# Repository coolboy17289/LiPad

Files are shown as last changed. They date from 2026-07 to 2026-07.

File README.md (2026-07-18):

# LiPad

# Features

## Hardware

- Custom-designed PCB
- Compact macropad layout
- RP2040-based controller support
- Mechanical key switches
- Rotary encoder with push button
- 14x SK6812 MINI addressable RGB LEDs
- Custom LED positioning for animations
- Designed using KiCad

## Firmware

LiPad uses:

- CircuitPython
- KMK Firmware
- NeoPixel RGB control

Current firmware features:

- Programmable key layers
- Media controls
- Rotary encoder volume control
- Encoder button actions
- RGB lighting effects
- Idle lighting mode
- Custom keyboard matrix support

---

# Project Structure

```
LiPad/
├── PCB/
│   ├── KiCad schematic files
│   ├── PCB layout files
│   └── 3D model files
│
├── Code/
│   ├── main.py
│   ├── kb.py
│   ├── code.py
│   └── requirements.txt
│
├── README.md
├── .gitignore
└── .vscode/
    └── settings.json
```

---

# Firmware

The LiPad firmware is separated into hardware configuration and keyboard behaviour.

## code.py

`code.py` is the CircuitPython startup file.

When the controller powers on, CircuitPython automatically runs this file to start the keyboard firmware.

---

## main.py

`main.py` contains the main functionality of LiPad.

It controls:

- Keyboard keymaps
- Layers
- Rotary encoder functions
- Encoder button behaviour
- RGB lighting effects
- Idle detection
- Keyboard events

The main firmware logic is designed to be easy to edit and customise without changing the hardware configuration.

---

## kb.py

`kb.py` defines the physical hardware of LiPad.

It contains:

- Matrix row pins
- Matrix column pins
- Diode orientation
- LED configuration
- LED count
- LED physical positions

This separation allows the firmware logic to change without needing to rewrite the hardware setup.

---

# Keyboard Layers

LiPad currently includes three layers.

## Layer 0 - Main

Default controls:

| Key | Function |
|---|---|
| Key 1 | Previous track |
| Key 2 | Play/Pause |
| Key 3 | Next track |

---

## Layer 1 - Utility

Additional shortcuts:

| Key | Function |
|---|---|
| Key 1 | Media select |
| Key 2 | Calculator |
| Key 3 | Windows Run |

# RGB Lighting

LiPad uses 14 SK6812 MINI addressable RGB LEDs.

The firmware supports multiple lighting modes:

## Solid

A breathing effect using the active layer colour.

## Rainbow

A moving rainbow animation across the LED layout.

## Wave

A wave animation based on the LED positions.

## Reactive

A bright reactive lighting mode.

## Idle

A low-power animation used when the keyboard has not been used for a period of time.

# PCB Design

The PCB for LiPad was designed using KiCad.

The PCB directory contains:

- Schematic files
- PCB layout
- Component footprints
- 3D model exports
- Design reports

The design was created with custom placement and routing to support the LiPad layout.

# Development

## Requirements

Development requires:

- Linux, Windows, or macOS
- Python 3
- Git
- VS Code recommended
- CircuitPython compatible controller

## Installing Development Tools

Navigate to the firmware folder:

```bash
cd Code
```

Install requirements:

```bash
python3 -m pip install -r requirements.txt
```

# Building Firmware

After preparing the CircuitPython controller:

1. Connect the board through USB
2. Enter bootloader mode
3. Copy the firmware files to the `CIRCUITPY` drive

Required files:

```
CIRCUITPY/
├── code.py
├── main.py
├── kb.py
└── lib/
```

# Future Plans

Possible future improvements:

- [ ] Custom LiPad case
- [ ] OLED display support
- [ ] More programmable layers
- [ ] Configuration software
- [ ] VIA/Vial compatibility
- [ ] Wireless support
- [ ] Improved RGB effects
- [ ] Build documentation
- [ ] Manufacturing files

# Contributing

Contributions are welcome.

If you would like to improve LiPad:

1. Fork the repository
2. Create a new branch

# License

LiPad is an open-source hardware and firmware project.

License information will be added before the first official release.

# Author

Created by **Lihan Badenhorst**

Project: **LiPad**

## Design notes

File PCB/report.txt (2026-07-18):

Plotted to '/home/Lihan/LiPad/PCB/gerbers/LiPad-F_Cu.gtl'.
Plotted to '/home/Lihan/LiPad/PCB/gerbers/LiPad-B_Cu.gbl'.
Plotted to '/home/Lihan/LiPad/PCB/gerbers/LiPad-F_Silkscreen.gto'.
Plotted to '/home/Lihan/LiPad/PCB/gerbers/LiPad-B_Silkscreen.gbo'.
Plotted to '/home/Lihan/LiPad/PCB/gerbers/LiPad-F_Mask.gts'.
Plotted to '/home/Lihan/LiPad/PCB/gerbers/LiPad-B_Mask.gbs'.
Plotted to '/home/Lihan/LiPad/PCB/gerbers/LiPad-Edge_Cuts.gm1'.
Created Gerber job file '/home/Lihan/LiPad/PCB/gerbers/LiPad-job.gbrjob'.
Info: Done.

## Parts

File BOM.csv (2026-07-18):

Component | Qty
XIAO RP2040 | 1
SK6812 Mini LEDs | 14
Rotary Encoder | 1
Cherry MX Switches | 9
PCB | 1
Diodes (1N4148) | 9
M3x8 Bolt | 4
1U Keycaps | 9
KMK Firmware | 1
PCB | 1
Case Top.stl | 1
Case Bottom.stl | 1
Knob.stl | 1

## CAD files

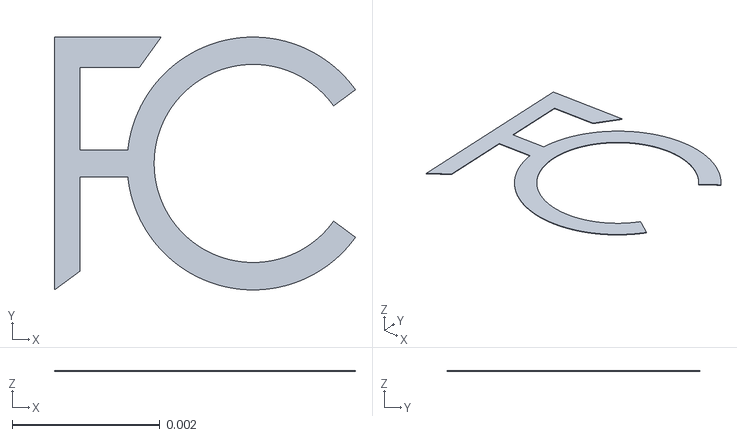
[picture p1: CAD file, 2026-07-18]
stl's/v1 do not use/Assembly 2 - Seeed Studio XIAO RP2040 v26 (20).stl
0.00407 x 0.00342 x 1e-05

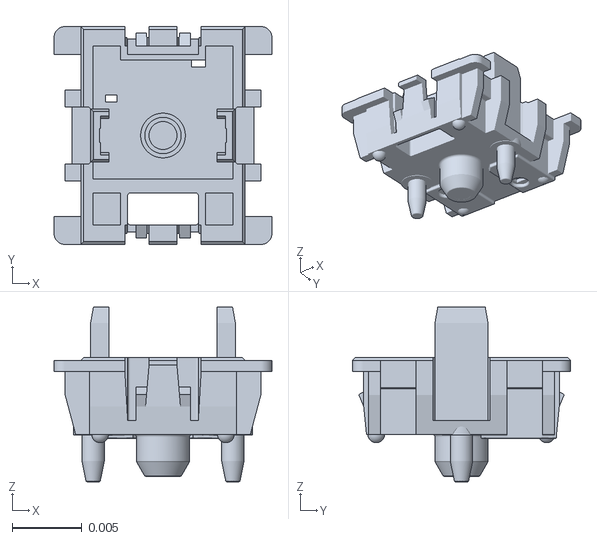
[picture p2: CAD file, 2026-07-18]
stl's/v1 do not use/Assembly 2 - SW_Cherry_MX_PCB_cp_6 (1).stl
0.0156 x 0.0156 x 0.0125

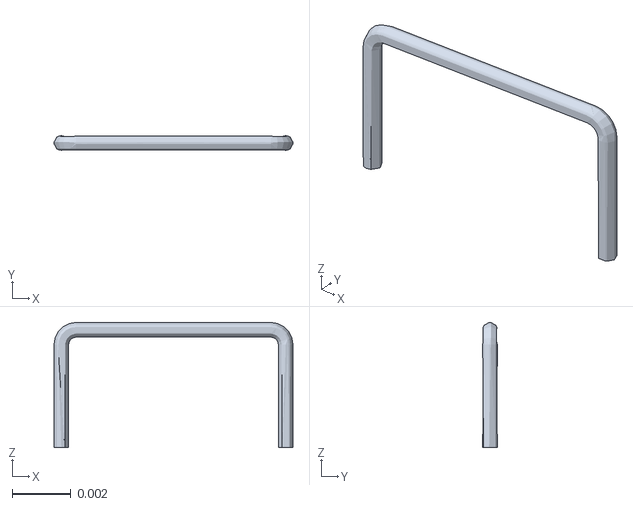
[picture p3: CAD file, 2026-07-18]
stl's/Main/Assembly 2 - D_DO-35_SOD27_P7.62mm_Horizontal.stl
0.00812 x 0.0005 x 0.00425

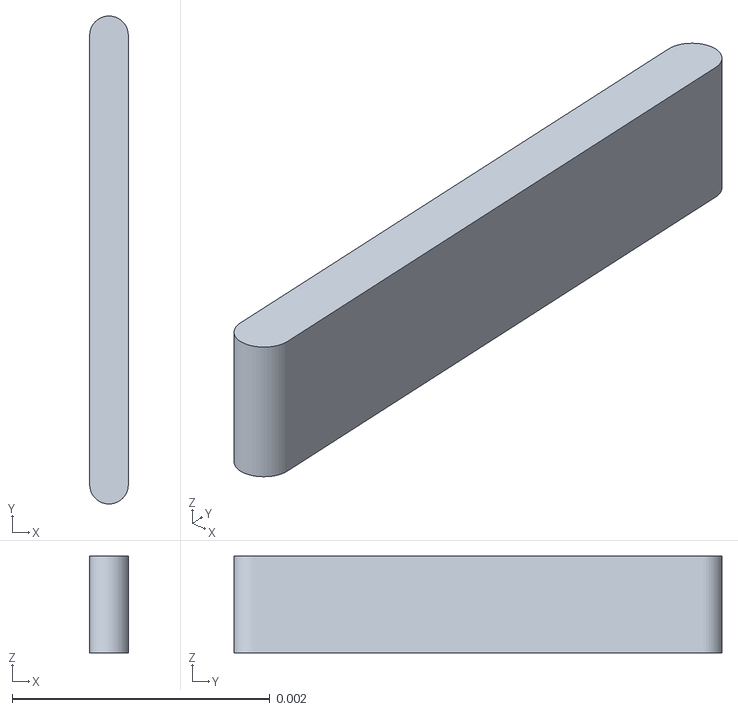
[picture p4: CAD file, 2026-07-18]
stl's/v1 do not use/Assembly 2 - Seeed Studio XIAO RP2040 v26 (24).stl
0.0003 x 0.00378 x 0.00075

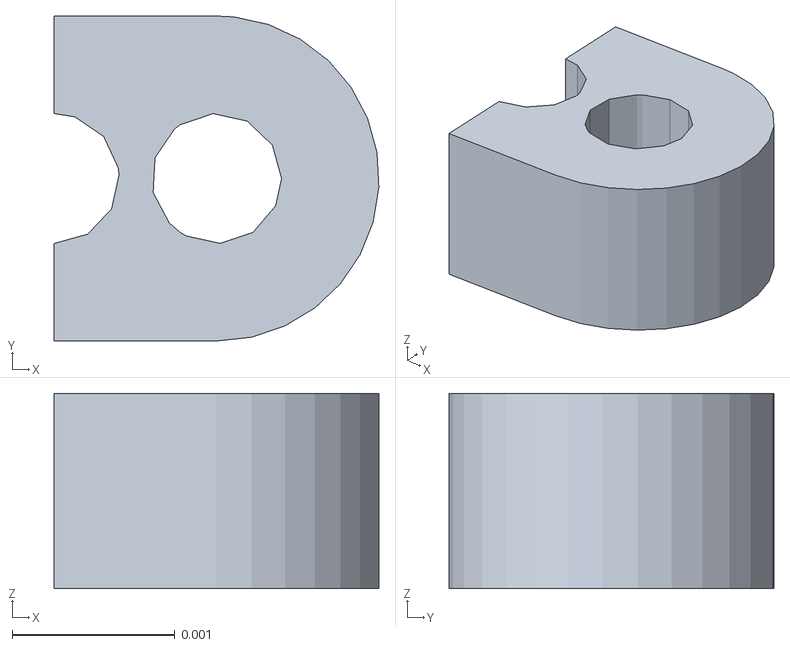
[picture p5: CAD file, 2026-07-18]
stl's/Main/Assembly 2 - Seeed Studio XIAO RP2040 v26 (57).stl
0.002 x 0.002 x 0.0012

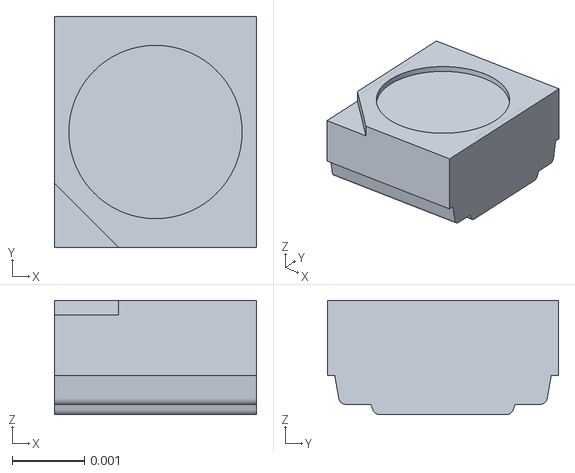
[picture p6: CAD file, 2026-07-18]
stl's/v1 do not use/Assembly 2 - Body_9.stl
0.0028 x 0.0032 x 0.00158

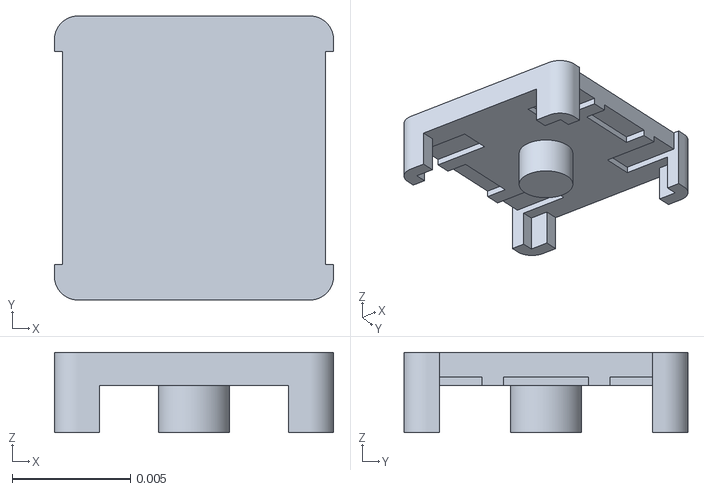
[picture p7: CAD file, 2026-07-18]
stl's/v1 do not use/Assembly 2 - Part 8.stl
0.0118 x 0.012 x 0.0034

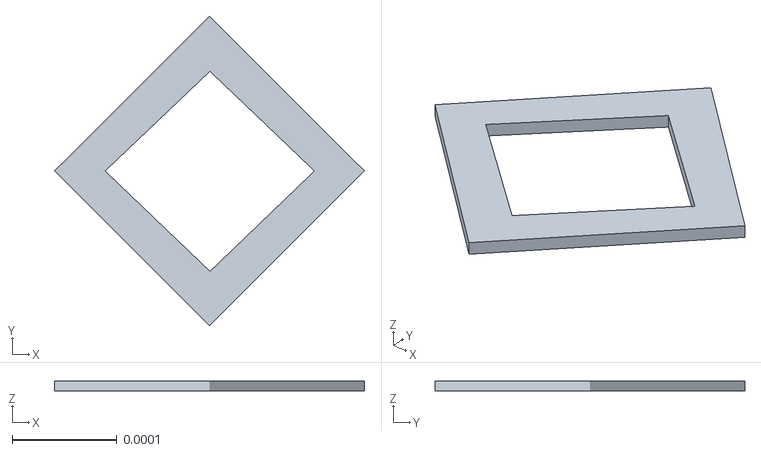
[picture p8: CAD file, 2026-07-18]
stl's/Main/Assembly 2 - Seeed Studio XIAO RP2040 v26 (34).stl
0.000295 x 0.000295 x 1e-05

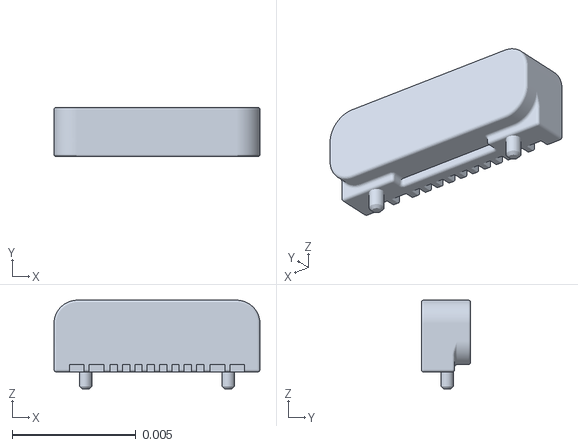
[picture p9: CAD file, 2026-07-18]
stl's/v1 do not use/Assembly 2 - Seeed Studio XIAO RP2040 v26 (21).stl
0.00834 x 0.002 x 0.00359

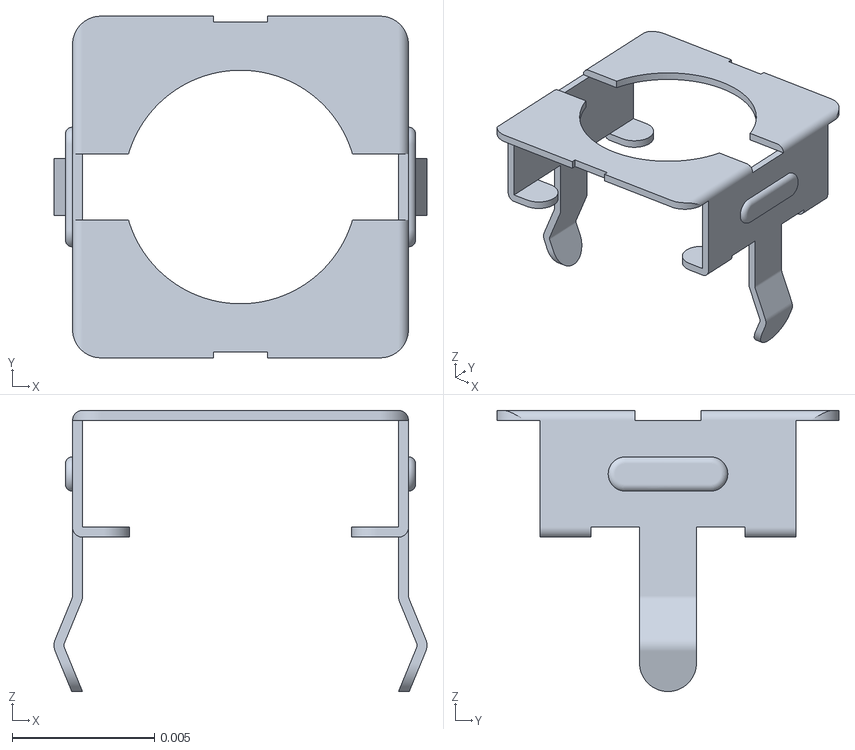
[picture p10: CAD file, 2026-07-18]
stl's/v1 do not use/Assembly 2 - Part 6.stl
0.0131 x 0.012 x 0.00987

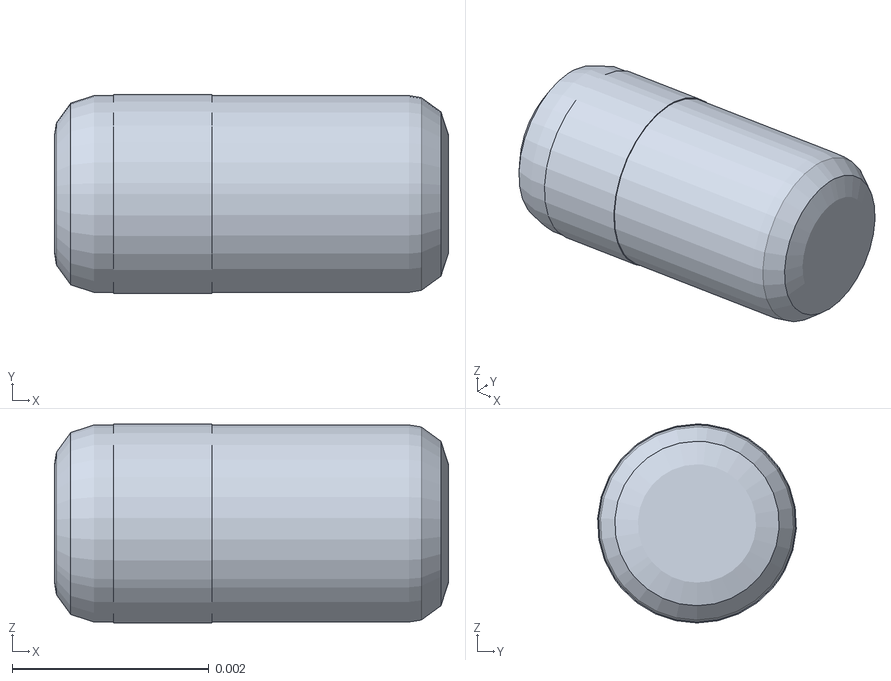
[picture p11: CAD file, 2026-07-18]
stl's/Main/Assembly 2 - D_DO-35_SOD27_P7.62mm_Horizontal_6.stl
0.004 x 0.00202 x 0.00202

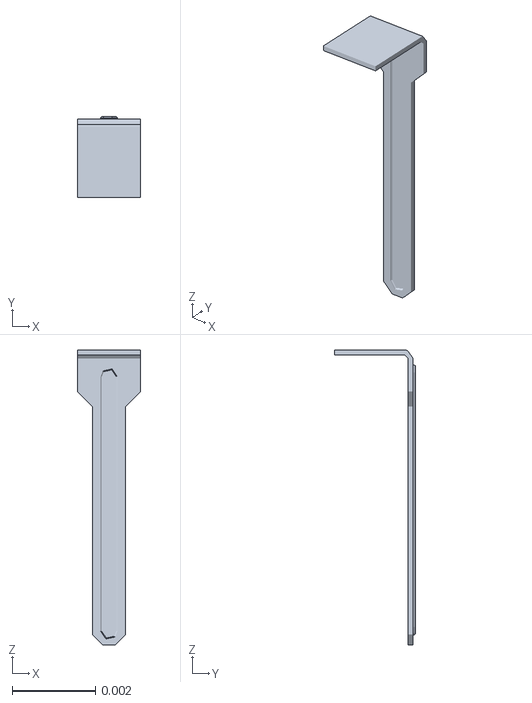
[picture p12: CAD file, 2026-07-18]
stl's/Main/Assembly 2 - Part 3.stl
0.0015 x 0.00193 x 0.00707

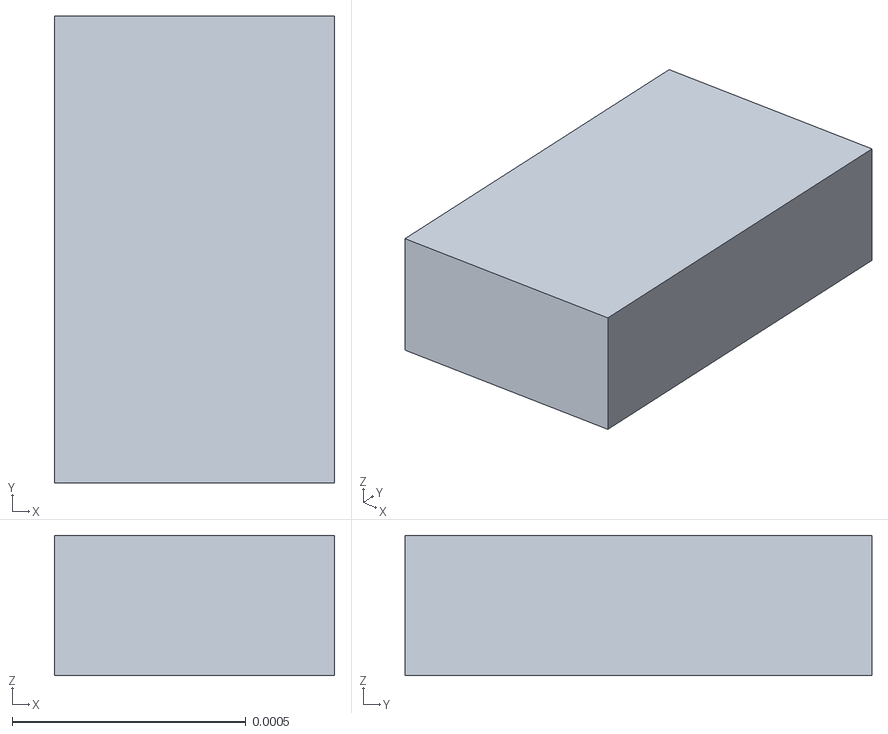
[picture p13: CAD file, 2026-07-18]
stl's/v1 do not use/Assembly 2 - Seeed Studio XIAO RP2040 v26 (74).stl
0.0006 x 0.001 x 0.0003

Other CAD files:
stl's/v1 do not use/Assembly 2 - Seeed Studio XIAO RP2040 v26 (53).stl
stl's/Main/Assembly 2 - Seeed Studio XIAO RP2040 v26 (42).stl
stl's/v1 do not use/Assembly 2 - Seeed Studio XIAO RP2040 v26 (82).stl
stl's/v1 do not use/Assembly 2 - Seeed Studio XIAO RP2040 v26 (67).stl
stl's/Main/Assembly 2 - Seeed Studio XIAO RP2040 v26 (51).stl
PCB/3D Models/MX_Switch.step
PCB/3D Models/SK6812MINI-E.step
PCB/3D Models/Seeed_Studio_XIAO_RP2040_v26.step
stl's/Main/Assembly 2 - Body.stl
stl's/Main/Assembly 2 - Body_1.stl
stl's/Main/Assembly 2 - Body_10.stl
stl's/Main/Assembly 2 - Body_11.stl
stl's/Main/Assembly 2 - Body_12.stl
stl's/Main/Assembly 2 - Body_13.stl
stl's/Main/Assembly 2 - Body_2.stl
stl's/Main/Assembly 2 - Body_3.stl
stl's/Main/Assembly 2 - Body_4.stl
stl's/Main/Assembly 2 - Body_5.stl
stl's/Main/Assembly 2 - Body_6.stl
stl's/Main/Assembly 2 - Body_7.stl
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

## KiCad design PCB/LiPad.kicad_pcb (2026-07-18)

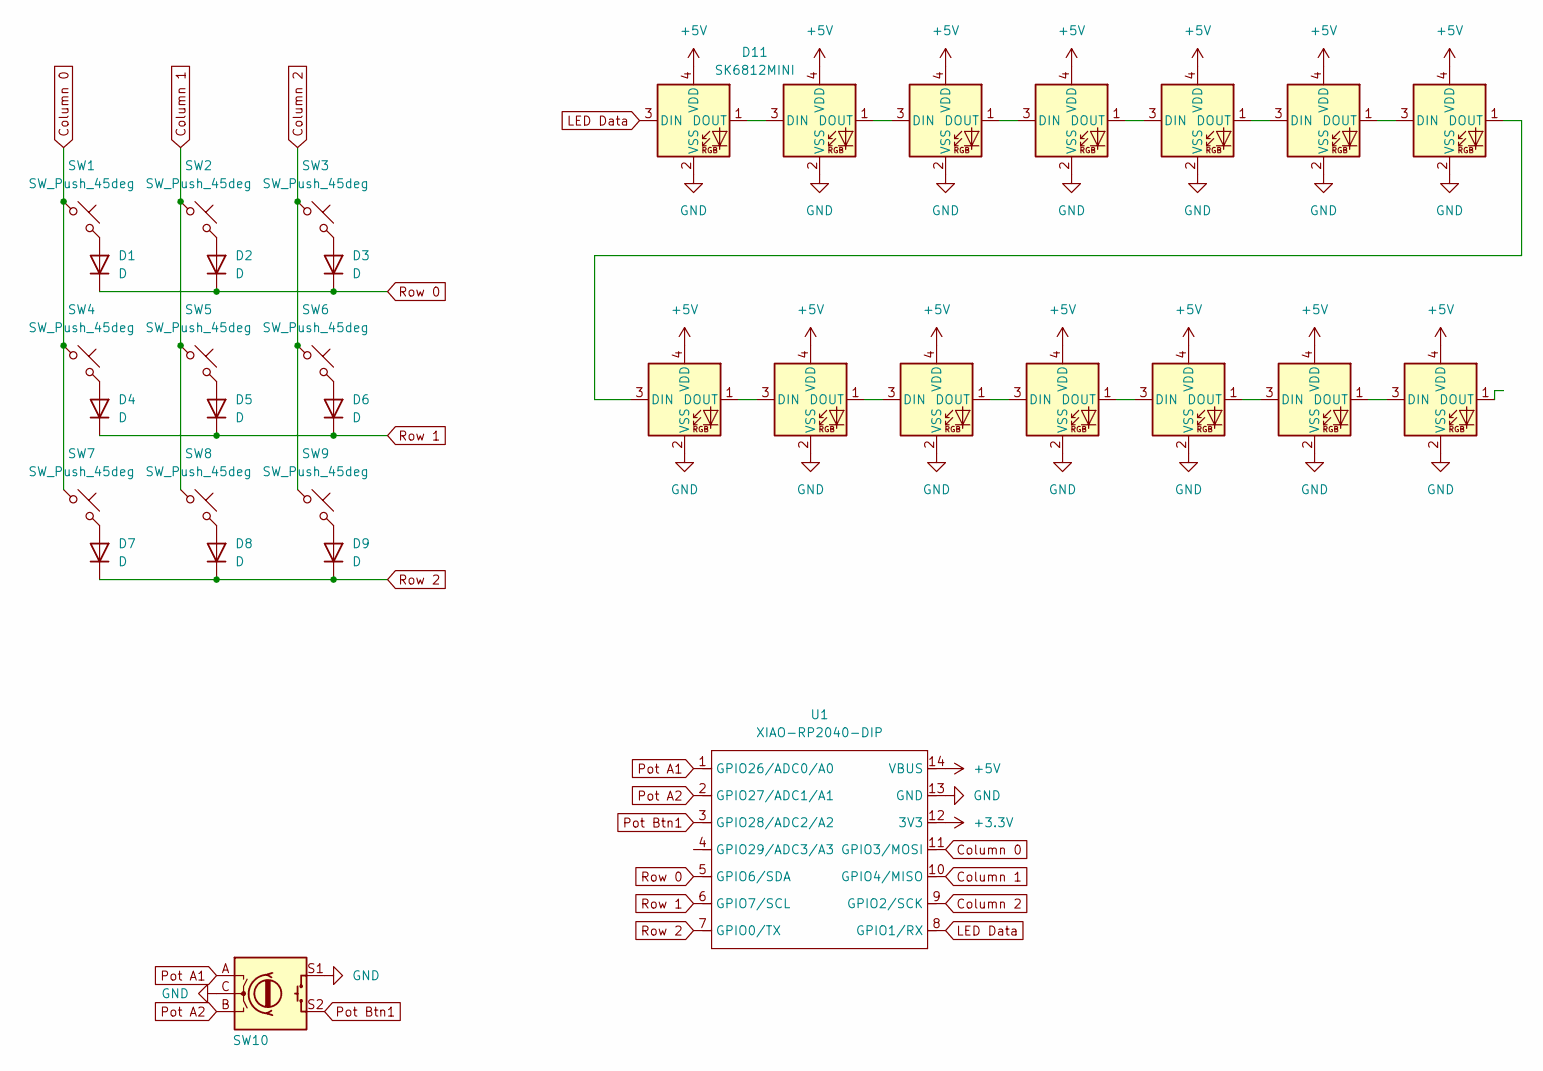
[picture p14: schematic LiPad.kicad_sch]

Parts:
D1, D2, D3, D4, D5, D6, D7, D8, D9: D; D_DO-35_SOD27_P7.62mm_Horizontal
D10, D11, D12, D13, D14, D15, D16, D17, D18, D19, D20, D21, D22, D23: SK6812MINI; LED_SK6812MINI_PLCC4_3.5x3.5mm_P1.75mm
SW1, SW2, SW3, SW4, SW5, SW6, SW7, SW8, SW9: SW_Push_45deg; SW_Cherry_MX_1.00u_PCB
SW10: RotaryEncoder_Switch; RotaryEncoder_Alps_EC11E-Switch_Vertical_H20mm
U1: XIAO-RP2040-DIP; XIAO-Generic-Hybrid-14P-2.54-21X17.8MM

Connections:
+3.3V: U1.12 (3V3)
+5V: D10.4 (VDD), D11.4 (VDD), D12.4 (VDD), D13.4 (VDD), D14.4 (VDD), D15.4 (VDD), D16.4 (VDD), D17.4 (VDD), D18.4 (VDD), D19.4 (VDD), D20.4 (VDD), D21.4 (VDD), D22.4 (VDD), D23.4 (VDD), U1.14 (VBUS)
Column 0: SW1.1, SW4.1, SW7.1, U1.11 (GPIO3/MOSI)
Column 1: SW2.1, SW5.1, SW8.1, U1.10 (GPIO4/MISO)
Column 2: SW3.1, SW6.1, SW9.1, U1.9 (GPIO2/SCK)
GND: D10.2 (VSS), D11.2 (VSS), D12.2 (VSS), D13.2 (VSS), D14.2 (VSS), D15.2 (VSS), D16.2 (VSS), D17.2 (VSS), D18.2 (VSS), D19.2 (VSS), D20.2 (VSS), D21.2 (VSS), D22.2 (VSS), D23.2 (VSS), SW10.C, SW10.S1, U1.13 (GND)
LED Data: D10.3 (DIN), U1.8 (GPIO1/RX)
unnamed: D1.2 (A), SW1.2
unnamed: D2.2 (A), SW2.2
unnamed: D3.2 (A), SW3.2
unnamed: D4.2 (A), SW4.2
unnamed: D5.2 (A), SW5.2
unnamed: D6.2 (A), SW6.2
unnamed: D7.2 (A), SW7.2
unnamed: D8.2 (A), SW8.2
unnamed: D9.2 (A), SW9.2
unnamed: D10.1 (DOUT), D11.3 (DIN)
unnamed: D11.1 (DOUT), D12.3 (DIN)
unnamed: D12.1 (DOUT), D13.3 (DIN)
unnamed: D13.1 (DOUT), D14.3 (DIN)
unnamed: D14.1 (DOUT), D15.3 (DIN)
unnamed: D15.1 (DOUT), D16.3 (DIN)
unnamed: D16.1 (DOUT), D17.3 (DIN)
unnamed: D17.1 (DOUT), D18.3 (DIN)
unnamed: D18.1 (DOUT), D19.3 (DIN)
unnamed: D19.1 (DOUT), D20.3 (DIN)
unnamed: D20.1 (DOUT), D21.3 (DIN)
unnamed: D21.1 (DOUT), D22.3 (DIN)
unnamed: D22.1 (DOUT), D23.3 (DIN)
Pot A1: SW10.A, U1.1 (GPIO26/ADC0/A0)
Pot A2: SW10.B, U1.2 (GPIO27/ADC1/A1)
Pot Btn1: SW10.S2, U1.3 (GPIO28/ADC2/A2)
Row 0: D1.1 (K), D2.1 (K), D3.1 (K), U1.5 (GPIO6/SDA)
Row 1: D4.1 (K), D5.1 (K), D6.1 (K), U1.6 (GPIO7/SCL)
Row 2: D7.1 (K), D8.1 (K), D9.1 (K), U1.7 (GPIO0/TX)

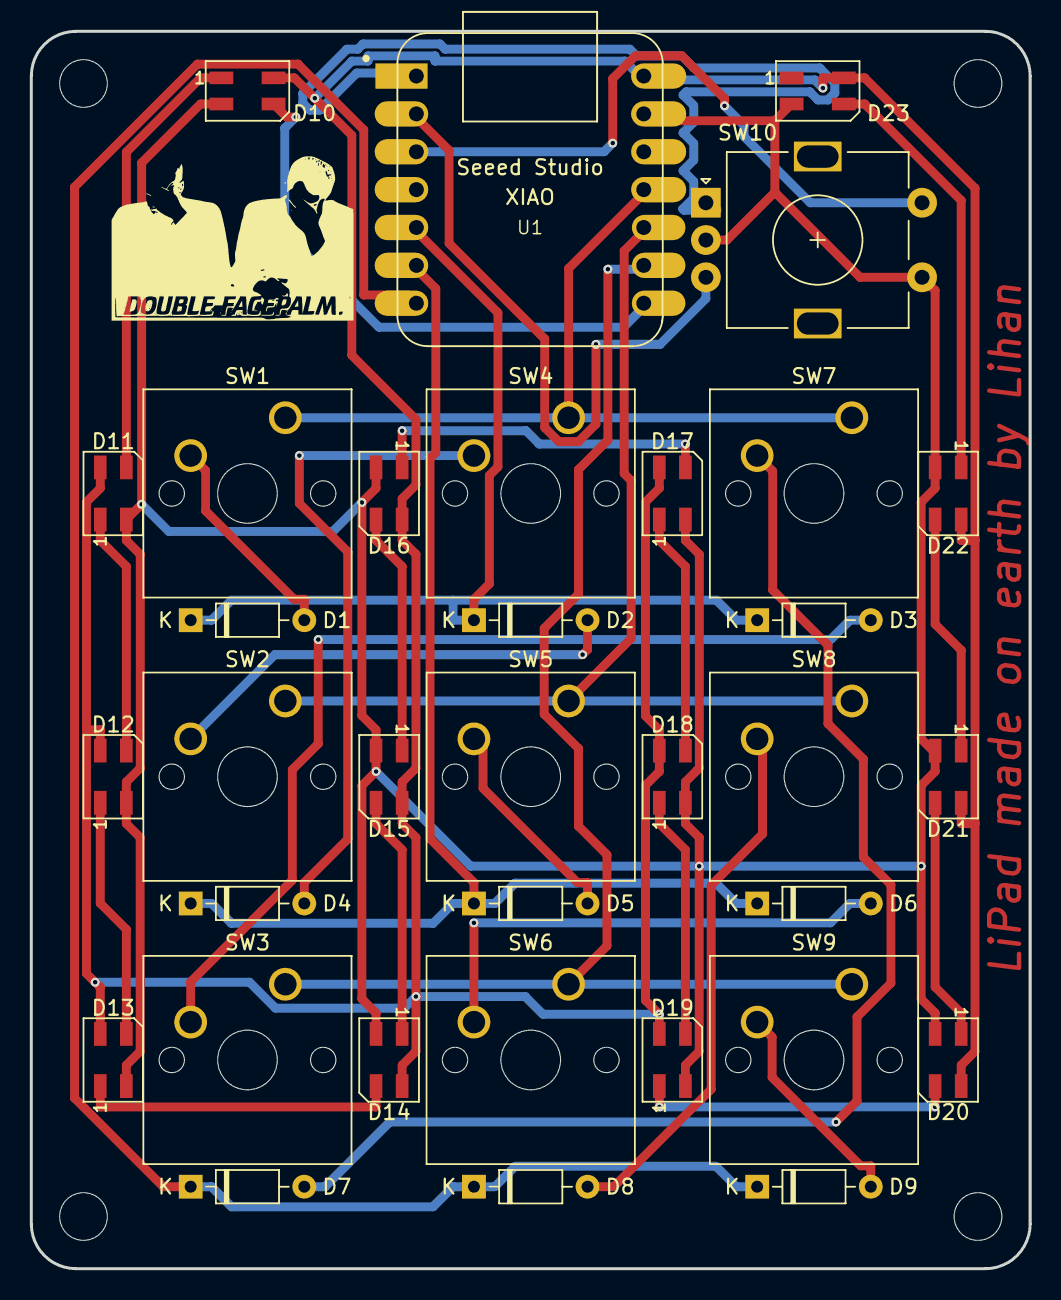
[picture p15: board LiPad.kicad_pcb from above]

Board: 2 copper layers, 67.0 x 83.0 mm, 38 parts (0 on the bottom side), 34 nets.

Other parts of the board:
HOLE1, HOLE2, HOLE3, HOLE4: 3.2mm_M3; MountingHole_3.2mm_M3

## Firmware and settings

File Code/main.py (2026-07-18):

import board
import time
import math
import digitalio

from kmk.keys import KC
from kmk.modules.layers import Layers
from kmk.modules.rotary_encoder import RotaryEncoderHandler

from kb import KMKKeyboard


keyboard = KMKKeyboard()


layers = Layers()
keyboard.modules.append(layers)


keyboard.keymap = [
    [
        KC.MRWD,
        KC.MPLY,
        KC.MFFD
    ],

    [
        KC.MSEL,
        KC.CALC,
        KC.LGUI(KC.R)
    ],

    [
        KC.LEFT,
        KC.RIGHT,
        KC.LGUI(KC.L)
    ]
]


encoder = RotaryEncoderHandler()
keyboard.modules.append(encoder)


encoder.pins = (
    (board.GP26, board.GP27, None),
)

encoder.divisor = 4

encoder.map = [
    ((KC.VOLD, KC.VOLU),)
]


encoder_button = digitalio.DigitalInOut(
    board.GP28
)

encoder_button.switch_to_input(
    pull=digitalio.Pull.UP
)


modes = [
    "solid",
    "rainbow",
    "wave",
    "reactive",
    "idle"
]


mode = 0


layer_hues = {
    0: 190,
    1: 120,
    2: 280
}


last_activity = time.monotonic()
idle_time = 120

button_last = False
button_press = 0


def hsv(h, s, v):
    h %= 360

    c = v * s
    x = c * (1 - abs((h / 60) % 2 - 1))
    m = v - c

    if h < 60:
        r, g, b = c, x, 0
    elif h < 120:
        r, g, b = x, c, 0
    elif h < 180:
        r, g, b = 0, c, x
    elif h < 240:
        r, g, b = 0, x, c
    elif h < 300:
        r, g, b = x, 0, c
    else:
        r, g, b = c, 0, x

    return (
        int((r + m) * 255),
        int((g + m) * 255),
        int((b + m) * 255),
        0
    )


def next_mode():
    global mode

    mode = (
        mode + 1
    ) % len(modes)


def render_leds():
    t = time.monotonic()

    hue = layer_hues.get(
        keyboard.active_layers[0],
        200
    )

    current = modes[mode]

    for i, (x, y) in enumerate(
        keyboard.led_positions
    ):

        if current == "solid":

            value = (
                math.sin(t * 1.5) + 1
            ) / 2

            keyboard.leds[i] = hsv(
                hue,
                0.9,
                value
            )


        elif current == "rainbow":

            keyboard.leds[i] = hsv(
                x * 25 + y * 20 + t * 40,
                1,
                1
            )


        elif current == "wave":

            value = (
                math.sin(t * 2 + x + y) + 1
            ) / 2

            keyboard.leds[i] = hsv(
                hue + value * 70,
                0.8,
                value
            )


        elif current == "reactive":

            keyboard.leds[i] = hsv(
                hue,
                1,
                1
            )


        elif current == "idle":

            value = (
                math.sin(t * 0.5) + 1
            ) / 2

            keyboard.leds[i] = hsv(
                200,
                0.5,
                value * 0.25
            )


    keyboard.leds.show()


def check_idle():
    global mode

    if time.monotonic() - last_activity > idle_time:
        mode = len(modes) - 1


def check_button():
    global button_last
    global button_press
    global last_activity

    pressed = not encoder_button.value

    if pressed and not button_last:
        button_press = time.monotonic()

    if not pressed and button_last:

        duration = (
            time.monotonic()
            -
            button_press
        )

        if duration > 1:
            keyboard.active_layers[0] = (
                keyboard.active_layers[0] + 1
            ) % 3

        else:
            next_mode()

        last_activity = time.monotonic()

    button_last = pressed


def tick():
    check_idle()
    check_button()
    render_leds()


keyboard.before_matrix_scan.append(tick)


keyboard.go()

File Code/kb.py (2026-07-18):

import board
import neopixel

from kmk.kmk_keyboard import KMKKeyboard as _KMKKeyboard
from kmk.scanners import MatrixScanner, DiodeOrientation


class KMKKeyboard(_KMKKeyboard):
    def __init__(self):
        super().__init__()

        self.col_pins = (
            board.GP3,
            board.GP4,
            board.GP2
        )

        self.row_pins = (
            board.GP6,
            board.GP7,
            board.GP0
        )

        self.diode_orientation = DiodeOrientation.COL2ROW

        self.matrix = MatrixScanner(
            column_pins=self.col_pins,
            row_pins=self.row_pins,
            diode_orientation=self.diode_orientation
        )

        self.encoder_button_pin = board.GP28

        self.num_leds = 14

        self.leds = neopixel.NeoPixel(
            board.GP1,
            self.num_leds,
            brightness=0.5,
            auto_write=False,
            pixel_order=neopixel.GRBW
        )

        self.led_positions = [
            (11, 0.5),
            (2, 27.5),
            (2, 46.5),
            (2, 65.5),
            (20.475, 27.5),
            (20.475, 46.5),
            (20.475, 65.5),
            (39.525, 27.5),
            (39.525, 46.5),
            (39.525, 65.5),
            (58, 27.5),
            (58, 46.5),
            (58, 65.5),
            (49.25, 0.5)
        ]

    def led_startup(self):
        for i in range(self.num_leds):
            self.leds[i] = (255, 255, 255, 0)
            self.leds.show()

        for i in range(self.num_leds):
            self.leds[i] = (0, 0, 0, 0)

        self.leds.show()

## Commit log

2026-07-18 updated pcb
    [LiPad.kicad_pcb]
2026-07-18 stls added
    [Assembly 2 - Body.stl, Assembly 2 - Body_1.stl, Assembly 2 - Body_10.stl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]
